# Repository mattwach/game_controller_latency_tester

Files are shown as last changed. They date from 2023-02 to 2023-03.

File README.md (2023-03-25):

# game_controller_latency_tester

This project provides a (couple of) hardware designs for interfacing a game
controller to a Raspberry PI (or similar) and automatically measuring the input
latency added by the controller.

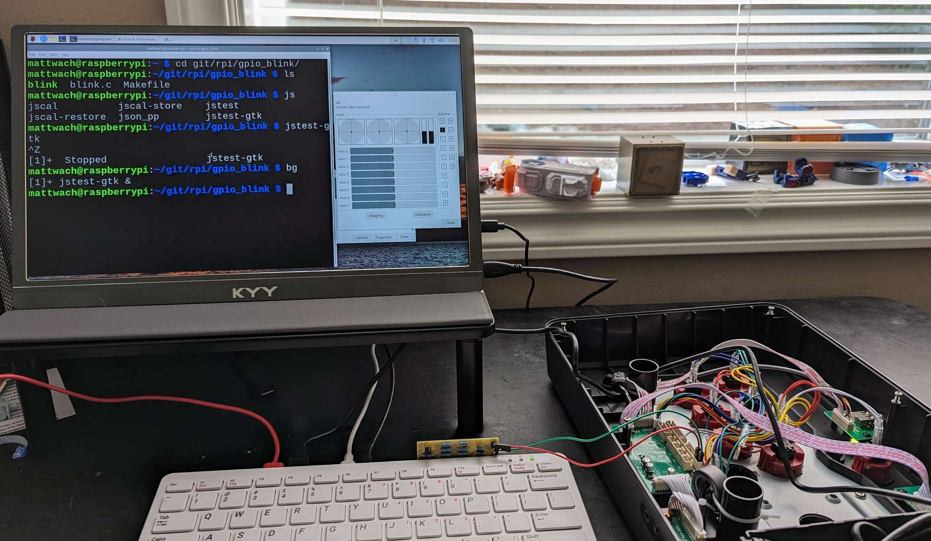
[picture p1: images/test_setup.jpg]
test setup


## What is input latency?

The "input latency" I'm referring to in this document is the amount of time
that passes between a button being pressed on the controller and application
(game) receiving the event.

This is the sum of all of the following:

   1. The game controller hardware signaling that the button is pressed
      (very fast)
   2. The game controller firmware processing this signal into a USB or
      bluetooth message (varies)
   3. The Raspberry PI USB/bluetooth hardware receiving the message and notifying the
      OS (usually fast)
   4. The Raspberry PI OS handling the message and passing it forward to
      the application (usually fast)

> "button" could also mean deflecting a stick.

## Raspberry PI verses Microcontroller Test Setup

Some setups, such as [this one](https://inputlag.science/controller/methodology)
use microcontroller hardware to handle #1, #3 and #4.  This project uses a
Raspberry PI instead.

One reason to use a microcontroller is more control over the environment.  A
Raspberry PI running Linux could get interrupted in the middle of a measurement
which would unfairly penalize the result.  That said, the PI has many
advantages as well:

   1. Even though the Raspberry PI *could* get interrupted, it's fairly simple
      to create a environment where this is not likely to happen.  For example
      you could run without a graphical environment or any services.  My own
      tests didn't even bother being careful with this and still got similar
      results as the [microcontroller version](https://inputlag.science/controller/methodology)
      testing the < 1ms [GP2040](https://github.com/FeralAI/GP2040) firmware.
   2. The Raspberry PI could be argued a more relevant test in some respects
      as it's using the same path that [RetroPie](https://retropie.org.uk/) would use.
   3. Supporting different configurations is much easier with Raspberry PI.
      For example, testing a bluetooth-based controller generally requires no
      additional hardware or setup.

## Other hardware options.

If Raspberry PI's are still hard to find, there are many alternative options.
The needed requirements are GPIO support and USB.  You *could* use a generic
PC with a USB to GPIO converter to send the needed trigger signals.  Something
like [this](https://www.adafruit.com/product/2264) or make-your-own with a PI Pico.

> Not using a Raspberry pi will likely require some tweaks to the
> source code provided in this project.

So in the text below, you can replace "Raspberry PI" with whatever you hapen to be using.

## Process Overview

   1. The Raspberry PI toggles a GPIO and notes the current time in microsecond
      resolution.
   2. The GPIO signals the game controller to sense that a button was pressed (or
      a stick was deflected)
   3. The controller sends a corresponding USB/Bluetooth message back to the
      Raspberry PI.
   4. Upon receiving the USB/Bluetooth message, the Raspberry PI notes how much
      time has passed since sending the GPIO

1-4 repeats many time (1000 or more) to build up statistics.

## Test Pattern

One test pattern would be to toggle the GPIOs very fast, like 1000 times per
second.  But since no human player could ever do this, it could be argued that
poor results in these setups might not be represent a real-world experience.

The test programs in this project try to set up a more "real world" situation
but toggling two GPIO channels at 10Hz (or 20 inputs per second).  The way this
is implemented is to toggle GPIO1 every 100ms and GPIO2 every 98ms.  This
creates a pattern that looks like this:

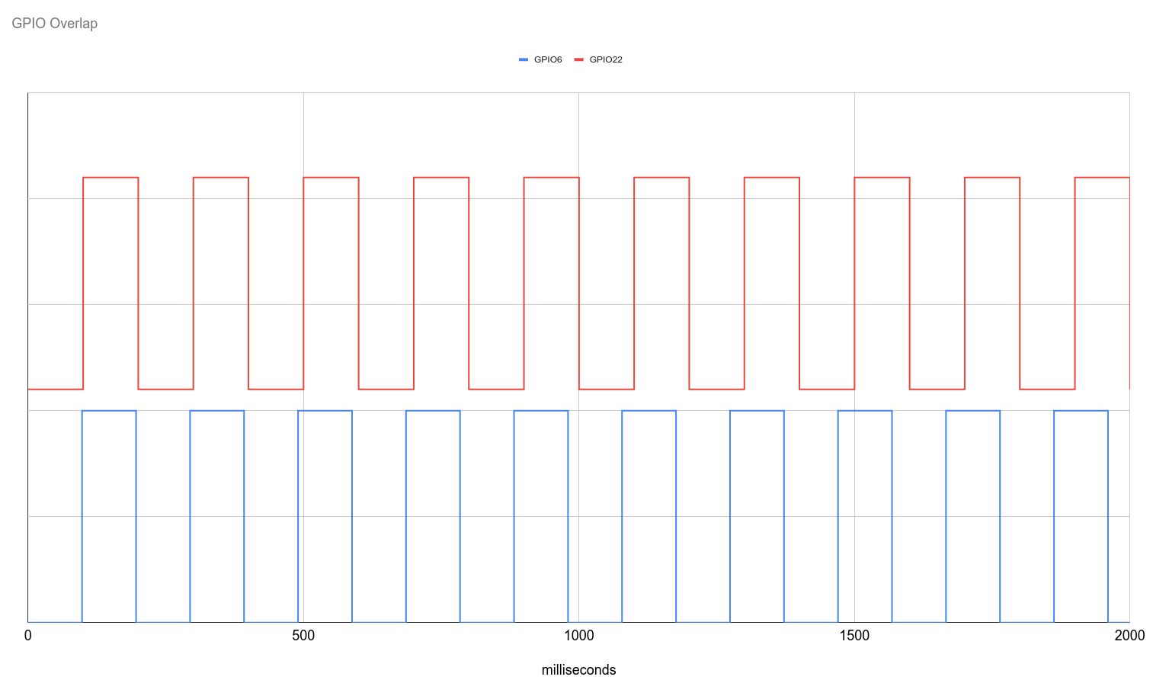
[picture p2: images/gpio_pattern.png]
GPIO Pattern


The game controller thus has to sometimes handle button being pressed at the
same time as could sometimes happen in real use.

## Interpreting the results

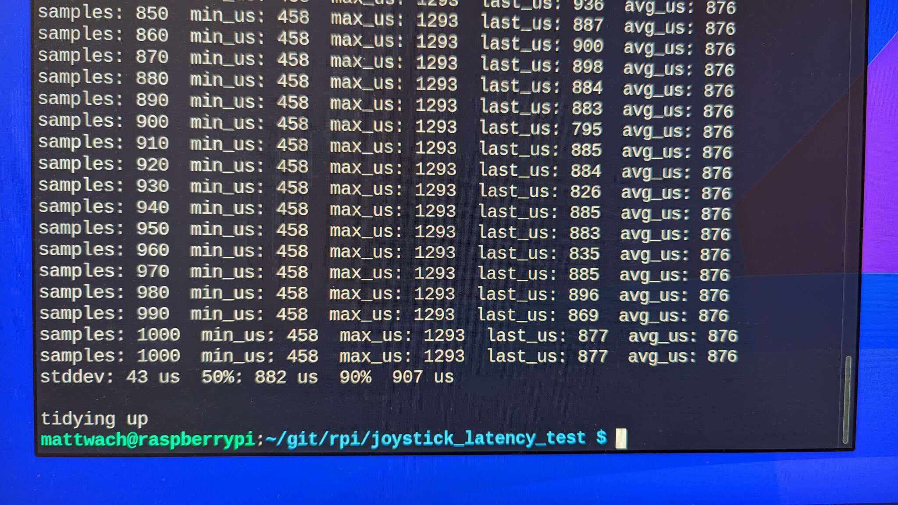
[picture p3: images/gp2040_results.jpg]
GP2040 results


The image above shows output statistics from `simple_latency_test` and the
[GP2040](https://github.com/FeralAI/GP2040) firmware, which has excellent
performance. 

The reported statistics will be as follows:

   * Median Latency: The "middle" latency value where half of the samples are
     larger and half of them are smaller.
   * Standard Deviation: A measure of latency variance.
   * 90% latency: A pessimistic-but-reasonable way to think about the latency
     It basically says that 90% of the time, you'll see less latency than the
     reported number.

### What is "bad" latency?

At 60 Hz, a video frame is (around 16ms).  So if your controller latency is > 16ms, then you will lose a frame due to the controller every time.  If your
latency is 8ms, you will lose a frame about half the time, and so on.

As far as how important a missed frame is, I invite you to draw your own
conclusions.  But here are some sources:

[This reaction time test](https://humanbenchmark.com/tests/reactiontime) shows
humans to be around 200ms on average.

But there is more to gaming that pure reaction.  Most games offer "cues" or
"tells" that are followed by predictable patterns.  Some games are fully
predictable, like playing a song.  When events can be predicted and tracked, it
becomes less about reaction time and more about "temporal precision".
[This particular study](https://jov.arvojournals.org/article.aspx?articleid=2213289)
measured temporal precision at just 6ms for some activities.

So it depends on many things but the studies above suggset there are cases
where low latency "matters" in terms of giving a player an additional advantage
at some games.

## Raspberry PI to Game Controller Interface Hardware

Let's start with the most straight-forward hardware approach. You *could* directly
connect a PI GPIO to a controller and in many cases it will work, but
there are risks:

   1. The Raspberry PI is 3.3V, the controller might be something different, such
      as 5V.  This voltage mismatch could damage the GPIO hardware of the PI.
   2. Connecting the PI to some unknown input could easily lead to situations
      where the PI is trying to power a ground connection to 3.3V or
      "current sink" a powered connection to ground.  These situations can
      lead to the controller and/or PI getting damaged.

Thus I suggest using protection circuitry to keep the PI and controller
isolated from each other and reduce the risks of damage.  I present two
protection designs: optocoupler based, and NFET based.

### NFET Design

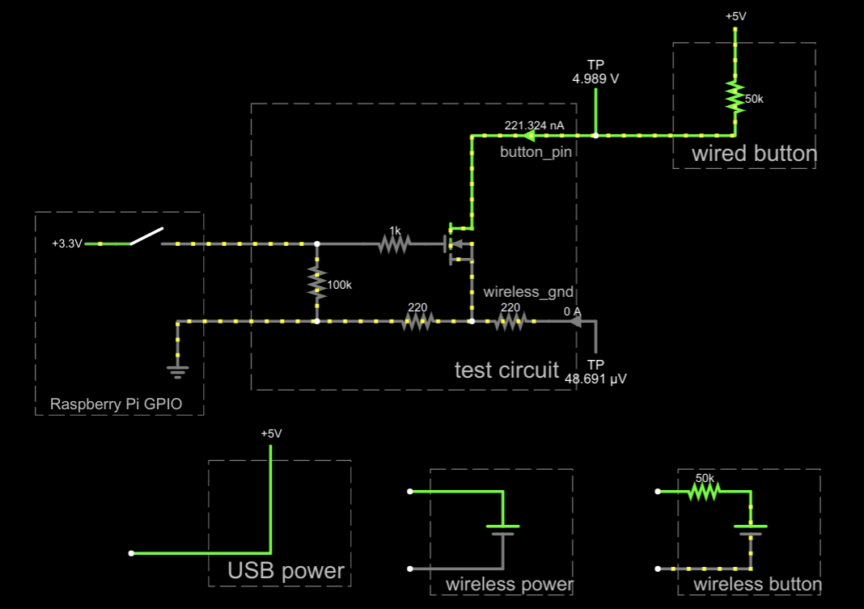
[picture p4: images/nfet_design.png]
NFET Design

[Playground Link](http://www.falstad.com/circuit/circuitjs.html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)

The NFET design has the advantage of easier hookup and faster operation.  The
disadvantage is that it will only work with ["pull up
resistor"](https://learn.sparkfun.com/tutorials/pull-up-resistors/all) style
buttons. If you unknowingly hook it to something else by mistake, no
damage will occur but the test will not be able to execute.  Pullup
configurations are more commonly used in design but some designs may have
reasons (or arbitrarily) decided to implement their buttons dfferently.

Another advantage of the FET, assumed pull up configuration is that the USB
cable (on USB controllers) can be used as the ground connection for the
test - this simplifies wiring and eliminates some types of wiring errors.

### Opcocoupler Design

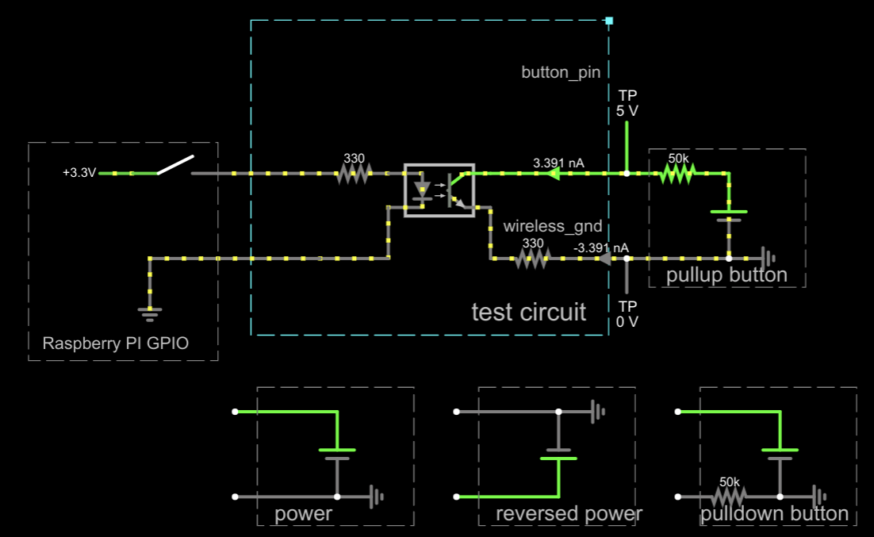
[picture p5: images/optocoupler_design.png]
Optocoupler Design

[Playground Link](http://www.falstad.com/circuit/circuitjs.html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)

The optocoupler based design will work with either pull up or pull down
configuratons, but you need to known which way the current flows through the
button and connect two wires per button. Getting any of this wrong
should not do any damage, but the test will fail to execute.  Optocouplers
are also quite a bit slower than FETs.  The one I had on-hand took around 2us
to activate and 100+us to turn itself off.  You can get faster ones, but need
to look at the datasheet when you pick one.  In comparison, FET's just take
a handful of ns to turn on/off.  

Going forward, I'll assume we are going with the NFET design.  If you need
the optocoupler one, then your hardware build will be different but the
software you run will be the same.

## Board Design

In the [latency_schematic/](latency_schematic) directory, I put together a
schematic of the NFET design:

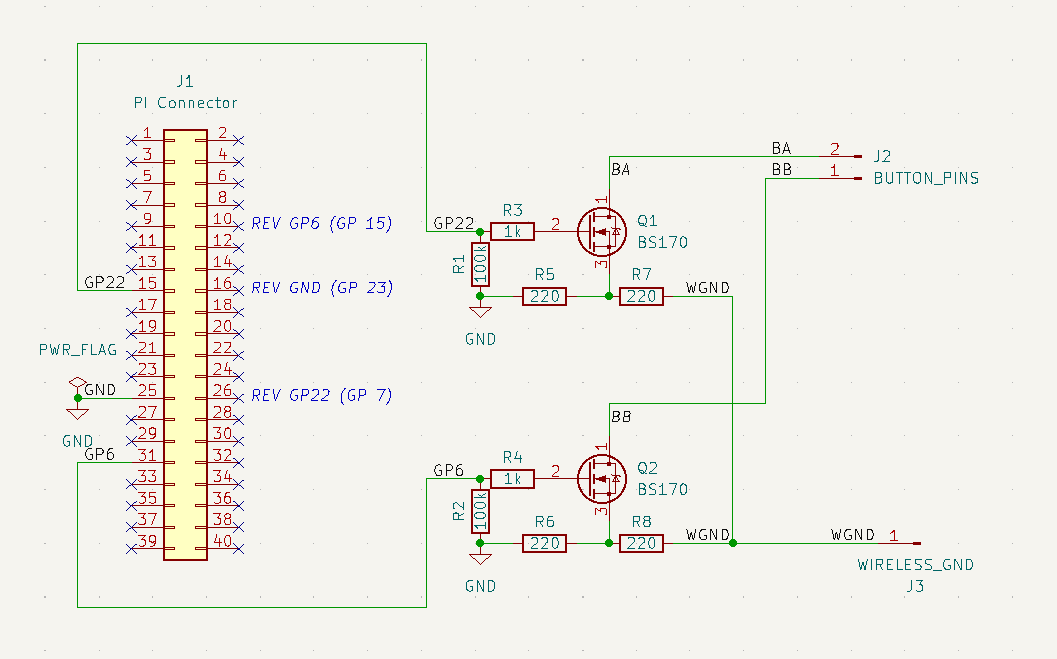
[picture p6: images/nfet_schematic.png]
nfet schematic


As well as a PCB layout that you can hand-wire, CNC cut, chemical etch or send
to a fab.

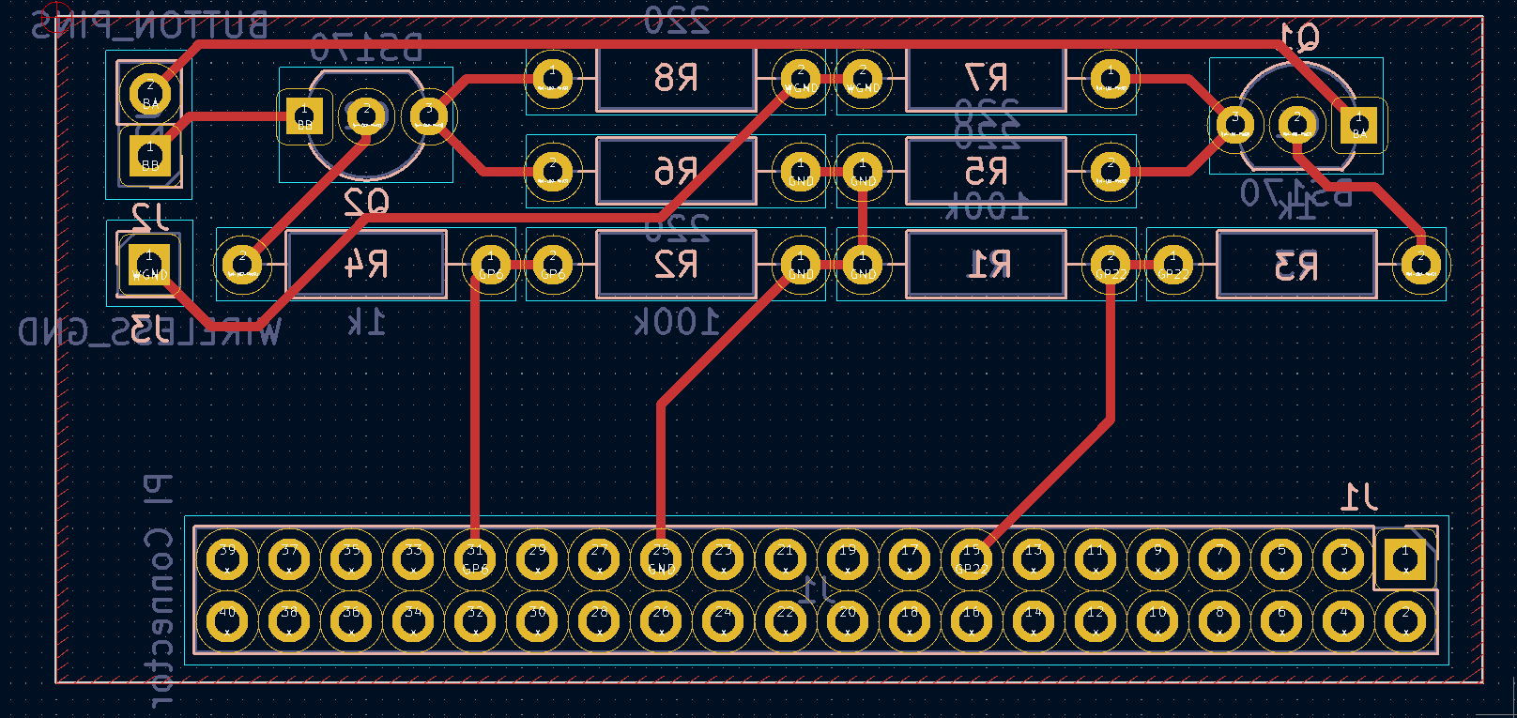
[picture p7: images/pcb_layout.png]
pcb layout


Here is my finished hardware:

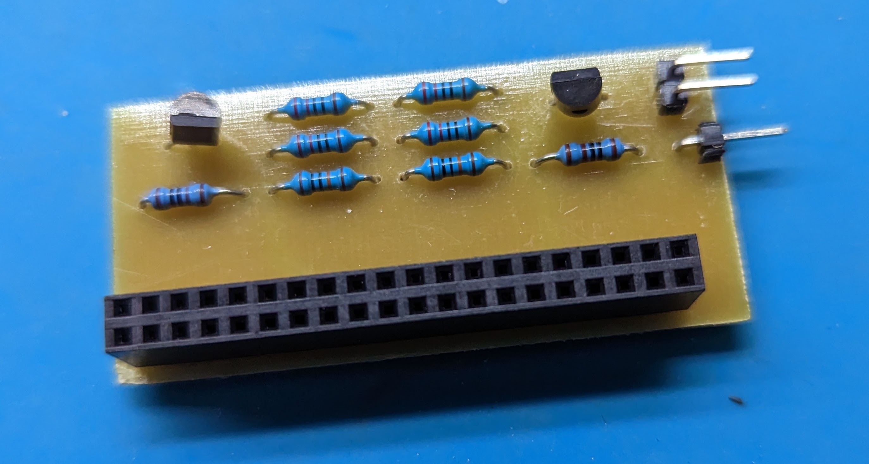
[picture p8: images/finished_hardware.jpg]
finished hardware


## Hardware Hookup

Here is the hardware connected to a Mayflash F500 arcade stick:

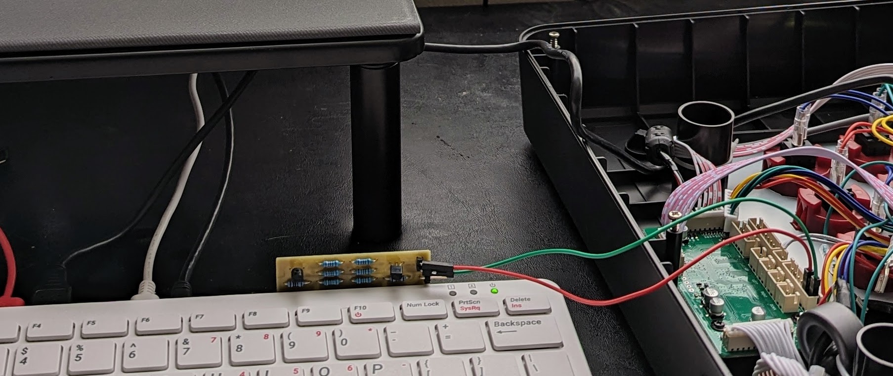
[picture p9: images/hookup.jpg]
hookup


One wire for each GPIO.  There is no need to connect a ground wire in this case
because there is a ground connection from the USB connection.  If this were
a wireless controller, then the additional ground wire would need to be
connected.

## Software Tools

Most of the tools you will build as a part of this project.  The process is
to type

    make

The standard Raspberry PI image should already contain the dependencies that
you will need.

### jstest-gtk

This is a commonly-availabe tool.  e.g. in Ubuntu you can just say

    sudo apt install jstest-gtk
    
to install the software.  This software can be used to verify that your
controller is connected and working.  It can also tell you the device number
(which is often /dev/input/js0 if you only have one connected).

### toggle_test

This tool was built when you executed `make`.  You run it like this

    ./toggle_test

The test simply toggles GPIO6 and GPIO22 every second.  If you have jstest-gtk running
and the hardware all hooked up, you will ideally see the software reporting that
buttons are being pressed.

### joystick_events

This utility is a less-advanced commandline variant of jstest-gtk.  You may not
need to run it at all but it can be useful as an alternative tool.  Usage is
simple:

    ./joystick_events

The tool assumes the device is `/dev/input/js0`.  This can be changed in `joystick_events.c`

### simple_latency_test

This is a single-channel version of the test that only uses GPIO22.  In my
testing, it gives the lowest latency numbers, especially in standard deviation.
It works by toggling a gpio, waiting for the response, then toggling another
one.  So it's a bit easier on the firmware than `multichannel_latency_test`.
Usage is again simple:

    ./simple_latency_test

### multichannel_latency_test

This version uses GPIO6 and GPIO22, toggling them in overlapping ways.  Usage
is again simple:

    ./multichannel_latency_test

## Taking It Further - Video Latency

With additional work, we can measure the latency from pushing a button all the
way to seeing something happen on the screen.  This takes the current latency
sources and adds the video pipeline and any processing the monitor may be doing.

> I'll just say that if you are connected to a TV, make sure it's in "game mode"
> to potentially avoid hundreds of additional ms of latency!

I didn't set this up, but here is a basic recipe for those who might want to:

1. You modify the software tools to draw a white rectangle on an otherwise
   black screen.
2. You use either a phototransistor or photodiode, pressed up close to the
   screen so that it can detect the change without picking up other
   light.
3. The phototransistor/photodiode drives a GPIO on the Rasperry PI.  The
   software monitors that GPIO to collect latency timing information.

Here is a basic phototransistor circuit that would be **combined** with one
of the circuits above (since you still want the ability to trigger the
buttons):

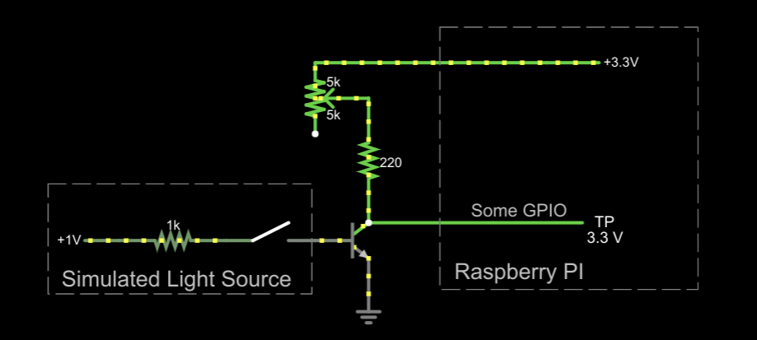
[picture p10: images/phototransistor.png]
phototransistor

[playground link](http://www.falstad.com/circuit/circuitjs.html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)

The potentiometer is used to change the sensitivity of the circuit.  Again, this
is just a starting point to give you some terms to search for.  Building up the
circuit above (or an alternate example you find) and testing it on a breadboard
is recommended before building anying permanent.

If you go with a photodiode, the circuit will be a bit different.  I also found
some [photodiode modules on Amazon](https://www.amazon.com/uxcell-Photosensitive-Terminals-Detection-Photodiode/dp/B07M8WS8TH) that look
easy to use.  Another option to consider.

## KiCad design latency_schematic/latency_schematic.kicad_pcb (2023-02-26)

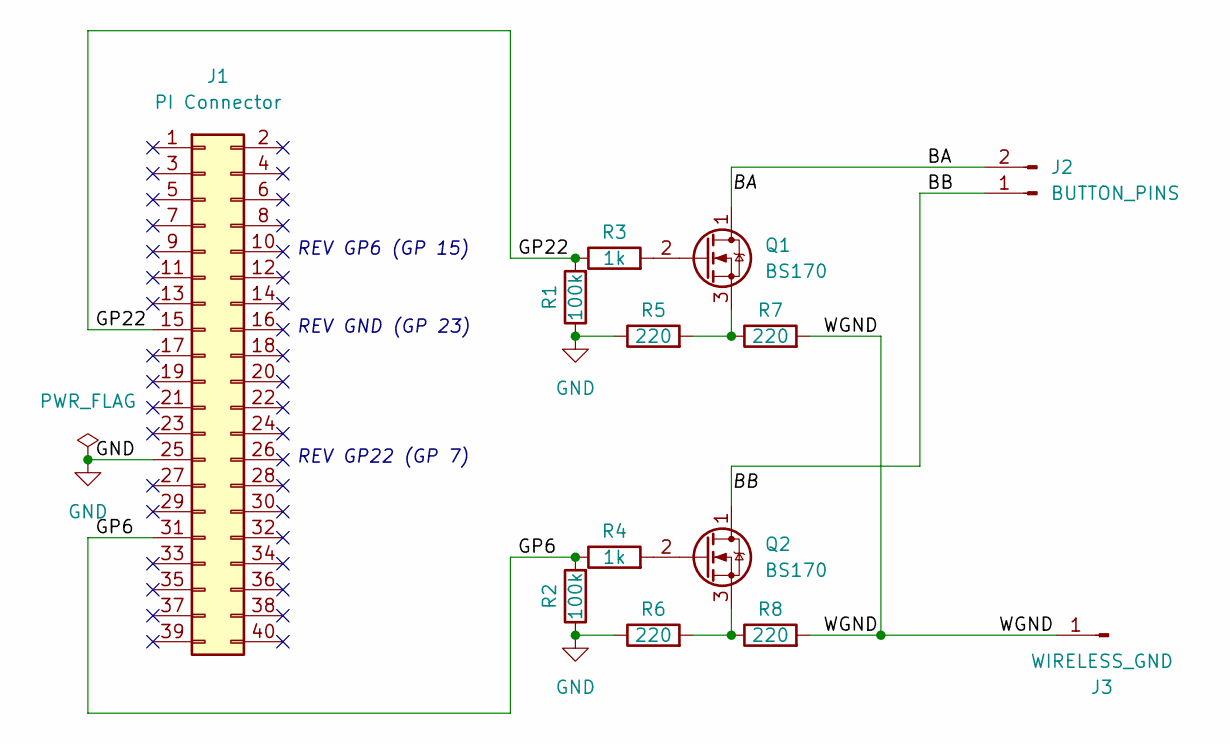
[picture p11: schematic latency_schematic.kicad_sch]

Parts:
J1: PI Connector; PinSocket_2x20_P2.54mm_Vertical
J2: BUTTON_PINS; PinSocket_1x02_P2.54mm_Vertical
J3: WIRELESS_GND; PinSocket_1x01_P2.54mm_Vertical
Q1, Q2: BS170; TO-92_Inline_Wide
R1, R2: 100k; R_Axial_DIN0207_L6.3mm_D2.5mm_P10.16mm_Horizontal
R3, R4: 1k; R_Axial_DIN0207_L6.3mm_D2.5mm_P10.16mm_Horizontal
R5, R6, R7, R8: 220; R_Axial_DIN0207_L6.3mm_D2.5mm_P10.16mm_Horizontal

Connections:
/BA: J2.2, Q1.1 (D)
/BB: J2.1, Q2.1 (D)
/GP6: J1.31, R2.2, R4.1
/GP22: J1.15, R1.2, R3.1
/WGND: J3.1, R7.2, R8.2
GND: J1.25, R1.1, R2.1, R5.1, R6.1
unnamed: Q1.2 (G), R3.2
unnamed: Q1.3 (S), R5.2, R7.1
unnamed: Q2.2 (G), R4.2
unnamed: Q2.3 (S), R6.2, R8.1

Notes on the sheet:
REV GP22 (GP 7)
REV GND (GP 23)
REV GP6 (GP 15)

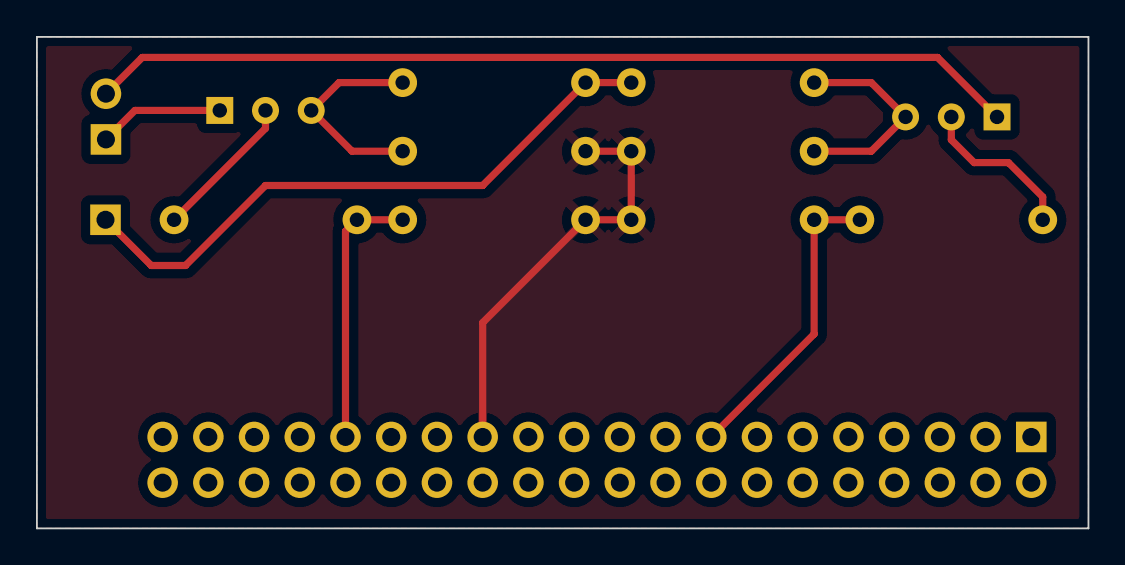
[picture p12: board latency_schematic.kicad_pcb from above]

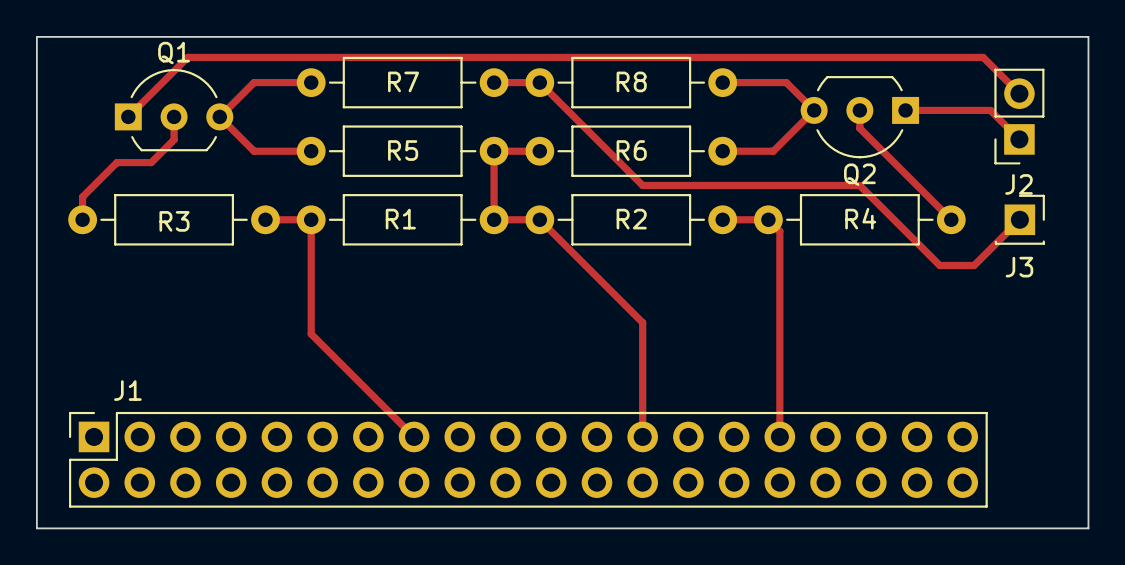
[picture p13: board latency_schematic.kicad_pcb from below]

Board: 2 copper layers, 58.4 x 27.3 mm, 13 parts (13 on the bottom side), 10 nets.

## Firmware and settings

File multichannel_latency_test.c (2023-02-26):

#include <fcntl.h>
#include <stdio.h>
#include <signal.h>
#include <pigpio.h>
#include <stdlib.h>
#include <string.h>
#include <unistd.h>
#include <time.h>
#include <inttypes.h>
#include <math.h>
#include <linux/joystick.h>

// how many samples to collect
#define SAMPLES_TO_COLLECT 1000

// approx how often to report
#define REPORT_MS 1000

// joystick device
#define JOYSTICK_DEVICE "/dev/input/js0"

// number of buttons (or axis)
#define BUTTON_COUNT 2

// how long to give unwanted joystick events to flush through
#define JS_FLUSH_TIME_MS 100

// trackig for a GPIO
struct GPIO {
  uint8_t pin;  // GPIO pin as defined by the raspberry pi
  uint8_t js_type;  // the associated type (button or axis)
  uint8_t js_number;  // button or axis number
  uint8_t toggle_value; // 1->high, 0->low
  uint32_t toggle_period_us;  // how often to toggle
  uint64_t last_toggle_us;  // timestamp for the last gpio toggle
  uint8_t responded;  // set to 0 when last_toggle_us is updated, 1 when an event happens   
} gpio[BUTTON_COUNT];

// Statistics to track
struct Stats {
  uint32_t max_latency_us;
  uint32_t min_latency_us;
  uint64_t total_latency_us;
  uint32_t sample_count;
  uint32_t sample_us[SAMPLES_TO_COLLECT];
  uint32_t events_lost;
} stats;

// Used to support ctrl-C
volatile int run = 0;

// joystick device file number
int js_fd = -1;

// Returns UNIX epoch as a millisecond value
static uint64_t get_ms(void) {
  struct timespec t;
  clock_gettime(CLOCK_REALTIME, &t);

  return (uint64_t)(t.tv_sec) * 1000 + (uint64_t)(t.tv_nsec) / 1000000;
}

// Returns UNIX epoch as a microsecond value
static uint64_t get_us(void) {
  struct timespec t;
  clock_gettime(CLOCK_REALTIME, &t);

  return (uint64_t)(t.tv_sec) * 1000000 + (uint64_t)(t.tv_nsec) / 1000;
}

// Reads in a single joystick event with the given timeout
static int read_js_event(struct js_event *event, uint32_t ms) {
    struct timeval tv;
    tv.tv_sec = ms / 1000;
    tv.tv_usec = (ms % 1000) * 1000;
    fd_set rd;
    FD_ZERO(&rd);
    FD_SET(js_fd, &rd);
    const int err = select(FD_SETSIZE, &rd, NULL, NULL, &tv);

    switch (err) {
      case 0:
        // timeout
        return err;
      case -1:
        // error
        return err;
      default:
        // have data
        break;
    }

    const ssize_t bytes = read(js_fd, event, sizeof(*event));
    if (bytes == sizeof(*event))
        return 1;

    // error reading event
    return -1;
}


// initialized a GPIO. returns 1 if successful, 0 otherwise
static int init_gpio(struct GPIO* g, uint8_t pin, uint32_t toggle_ms) {
  memset(g, 0, sizeof(*g));
  g->pin = pin;
  g->toggle_period_us = toggle_ms * 1000;

  gpioSetMode(pin, PI_OUTPUT);

  // first, a throw-away event becuase we don't know if the
  // pre-initialized gpio was in a pullup or pull-down configuration
  gpioWrite(pin, PI_HIGH);
  struct js_event event;
  int status = 1;
  for (int i=0; (status == 1) && (i<1000); ++i) {
    status = read_js_event(&event, JS_FLUSH_TIME_MS);
  }

  if (status != 0) {
    printf("gave up trying to flush joystick events: %d.\n", status);
    return 0;
  }

  // now send the "real" event from which we will determine the type and number
  gpioWrite(pin, PI_LOW);
  status = read_js_event(&event, JS_FLUSH_TIME_MS);
  if (status == 0) {
    // try again
    status = read_js_event(&event, JS_FLUSH_TIME_MS);
  }
  if (status == 0) {
    printf(
        "Did not receive js event after toggling gpio %u.  Consider running "
        "jstest-gtk and rechecking connections\n", pin);
    return 0;
  }
  if (status == -1) {
    printf("error while waiting for event from gpio %u\n", pin);
    return 0;
  }
  char* type_str = "unknown";
  if (event.type == JS_EVENT_BUTTON) {
    type_str = "button";
  } else if (event.type == JS_EVENT_AXIS) {
    type_str = "axis";
  } else {
    printf("Unexpected event type from gpio %u: %u\n", pin, event.type);
    return 0;
  }

  g->js_type = event.type;
  g->js_number = event.number;
  printf(
      "Initialized GPIO %u:  type: %s  number: %u\n", pin, type_str, g->js_number);
  return 1;
}

// signal handler callback, when ctrl-c is pressed
static void stop(int signum) {
  run = 0;
}

// stops using GPIO
static void stopGPIO(void) {
  printf("\ntidying up\n");
  for (int i=0; i<BUTTON_COUNT; ++i) {
    gpioSetMode(gpio[i].pin, PI_INPUT);
  }
  gpioTerminate();
}

// initialize GPIO and joystick.  Returns 0 if successful.
static int init() {
  memset(&stats, 0, sizeof(stats));
  stats.min_latency_us = 10000000;  // just some large value

  js_fd = open(JOYSTICK_DEVICE, O_RDONLY);
  if (js_fd == -1) {
    perror("Could not open JOYSTICK_DEVICE");
    return -1;
  }

  if (gpioInitialise() < 0) {
    printf("gpio init failed\n");
    close(js_fd);
    return -1;
  }

  gpioSetSignalFunc(SIGINT, stop);
  if (!init_gpio(gpio + 0, 22, 98)) {
    return -1;
  }
  if (!init_gpio(gpio + 1, 6, 100)) {
    return -1;
  }
  printf("ctrl-c to stop, or wait for %d samples\n", SAMPLES_TO_COLLECT);
  return 0;
}

// Prints the current stats to stdout
static void report_running_stats(void) {
  printf("samples: %u  min_us: %u  max_us: %u  last_us: %u  avg_us: %u  lost_events: %u\n",
      stats.sample_count,
      stats.min_latency_us,
      stats.max_latency_us,
      stats.sample_count > 0 ? stats.sample_us[stats.sample_count - 1] : 0,
      (uint32_t)(stats.total_latency_us / stats.sample_count),
      stats.events_lost);
}

// calculate standard deviation
static uint32_t calculate_std_dev(void) {
  const int32_t average_latency = (int32_t)(stats.total_latency_us / stats.sample_count);
  double squared_sum = 0;
  for (int i=0; i<stats.sample_count; ++i) {
    const int32_t delta = (int32_t)(stats.sample_us[i]) - average_latency;
    squared_sum += delta * delta;
  }
  const double std_dev = sqrt(squared_sum / stats.sample_count);
  return (uint32_t)std_dev;
}

static int qsort_compare_function(const void *a, const void *b) {
  const uint32_t *x = (uint32_t *) a;
  const uint32_t *y = (uint32_t *) b;
  return *x - *y;
}

// prints stats after all samples are collected
static void report_final_stats(void) {
  report_running_stats();
  if (stats.sample_count == 0) {
    return;
  }

  const uint32_t std_dev = calculate_std_dev();

  // calculate median and 90%
  qsort(
      stats.sample_us,
      stats.sample_count,
      sizeof(stats.sample_us[0]),
      qsort_compare_function);
  const uint32_t percent50 = stats.sample_us[stats.sample_count / 2];
  const uint32_t percent90 = stats.sample_us[stats.sample_count * 9 / 10];
  printf(
      "stddev: %u us  50%%: %d us  90%%  %d us\n",
      std_dev,
      percent50,
      percent90);
}

static void check_for_toggle(struct GPIO* g, uint64_t time_us) {
  if (time_us < (g->last_toggle_us + g->toggle_period_us)) {
    // not yet
    return;
  }

  if (!g->responded && (g->last_toggle_us > 0)) {
    // event was never received
    ++stats.events_lost;
  }

  g->toggle_value = 1 - g->toggle_value;
  gpioWrite(g->pin, g->toggle_value ? PI_HIGH : PI_LOW);
  g->last_toggle_us = get_us();
  g->responded = 0;
}

static void handle_js_event(const struct js_event* event) {
  struct GPIO* g = NULL;
  for (int i=0; (g == NULL) && (i<BUTTON_COUNT); ++i) {
    if ((gpio[i].js_type == event->type) &&
        (gpio[i].js_number == event->number)) {
      g = gpio + i;
    }
  }

  if (g == NULL) {
    return;
  }

  g->responded = 1;
  const uint64_t end_us = get_us(); 
  const uint32_t sample_us = end_us - g->last_toggle_us;
  stats.sample_us[stats.sample_count] = sample_us;
  stats.total_latency_us += sample_us;
  if (sample_us < stats.min_latency_us) {
    stats.min_latency_us = sample_us;
  }
  if (sample_us > stats.max_latency_us) {
    stats.max_latency_us = sample_us;
  }
  if (stats.sample_count < SAMPLES_TO_COLLECT) {
    ++stats.sample_count;
  }
}

static void loop(void) {
  const uint64_t time_us = get_us();
  int i;

  for (i = 0; i < BUTTON_COUNT; ++i) {
    check_for_toggle(gpio + i, time_us);
  }

  // wait for a js event until 1ms with no events has passed
  int state = 1;
  struct js_event event;
  while (state == 1) {
    state = read_js_event(&event, 1);
    if (state == -1) {
      printf("error reading js_event\n");
      run = 0;
    }
    if (state == 1) {
      handle_js_event(&event);
    }
  }
}

int main(int argc, char *argv[]) {
  if (init()) {
    return 1;
  }

  run = 1;
  uint64_t next_report_ms = get_ms() + REPORT_MS;
  while (run && (stats.sample_count < SAMPLES_TO_COLLECT)) {
    loop();
    // check for a report
    const uint64_t time_ms = get_ms();
    if (time_ms >= next_report_ms) {
      report_running_stats();
      next_report_ms = time_ms + REPORT_MS;
    }
  }

  report_final_stats();

  // finish up
  stopGPIO();
  close(js_fd);

  return 0;
}

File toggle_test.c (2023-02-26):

#include <stdio.h>
#include <signal.h>

#include <pigpio.h>

// PI GPIO's we are using for the buttons
#define GPIO1 6
#define GPIO2 22

// Handles Ctrl-C exits
volatile int run = 0;
static void stop(int signum) {
  run = 0;
}

int main(int argc, char *argv[]) {
  if (gpioInitialise() < 0) {
    printf("init failed\n");
    return -1;
  }

  gpioSetMode(GPIO1, PI_OUTPUT);
  gpioSetMode(GPIO2, PI_OUTPUT);

  gpioSetSignalFunc(SIGINT, stop);
  printf("ctrl-c to stop\n");

  run = 1;
  while (run) {
    gpioWrite(GPIO1, PI_HIGH);
    time_sleep(1);
    gpioWrite(GPIO2, PI_HIGH);
    time_sleep(1);
    gpioWrite(GPIO1, PI_LOW);
    time_sleep(1);
    gpioWrite(GPIO2, PI_LOW);
    time_sleep(1);
  }

  printf("\ntidying up\n");
  gpioSetMode(GPIO1, PI_INPUT);
  gpioSetMode(GPIO2, PI_INPUT);
  gpioTerminate();
  return 0;
}
